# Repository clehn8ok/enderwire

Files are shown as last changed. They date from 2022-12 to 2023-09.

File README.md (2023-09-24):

# enderwire

This is an adaption of https://github.com/thomasfjen/enderwire_nonpro Files, with the following changes:
- Custom Toolhead -> Orbiter2 with a Rapido Hotend 
  - based on the Apogee Toolhead adapted onto the SW Carriage 
- right motor mount modified
  - shifts the whole motor towards the Z gantry, since the belt was not aligned with the OG mounts 
- simpler Enclosure design with only Acrylic, no double sided tap, everything is screwed 
- custom hinges, which open 180° 
- y carriage has now the holes for the cablechain in the right spot

Full build video:https://youtu.be/0t4zVtzr5Jg

2022-12-23_13h25_12
thumbnail_CL_3DPRINTER_YT






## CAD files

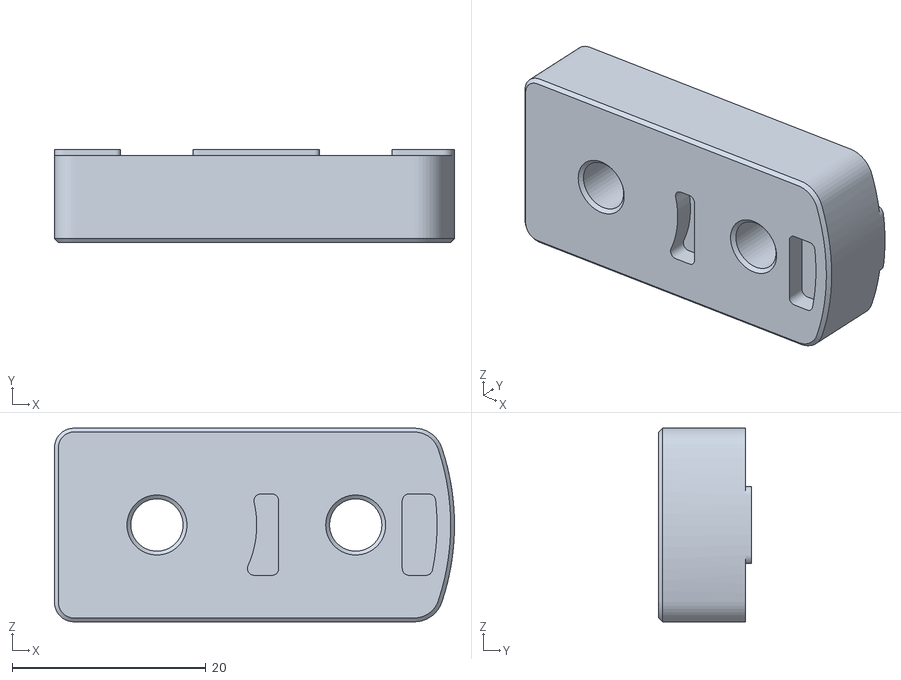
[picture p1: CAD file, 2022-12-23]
STLs/upperIdlerLH.stl
41.3 x 9.60 x 20.0

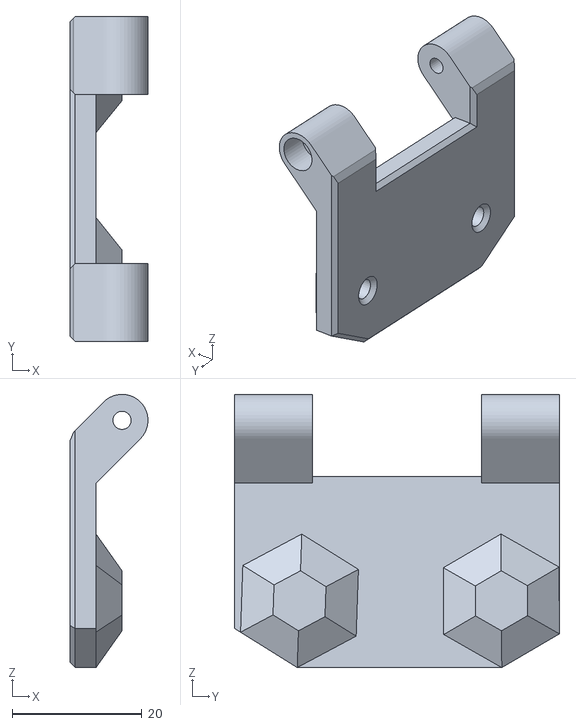
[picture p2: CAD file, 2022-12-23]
STLs/hinge2.stl
12.0 x 50.0 x 42.0

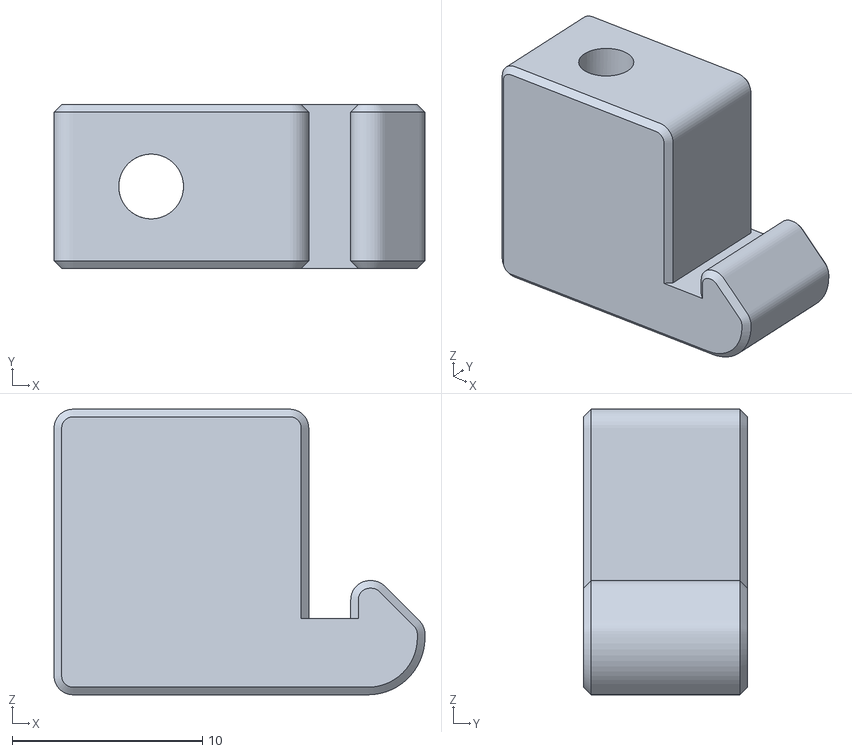
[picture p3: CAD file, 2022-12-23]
STLs/tensionerR.stl
19.5 x 8.60 x 15.0

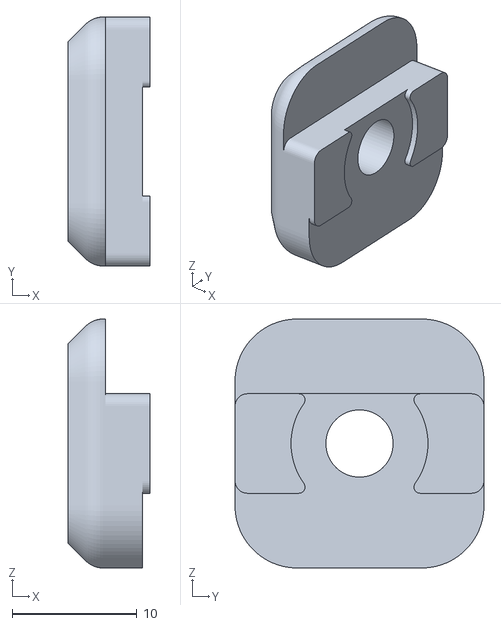
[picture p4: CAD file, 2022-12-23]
STLs/enclosureClip_L1.stl
6.60 x 20.0 x 20.0

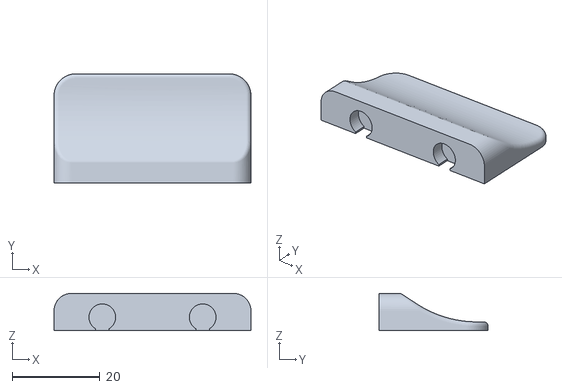
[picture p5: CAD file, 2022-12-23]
STLs/topDoor_magnetHOlder.stl
45.0 x 25.0 x 8.50

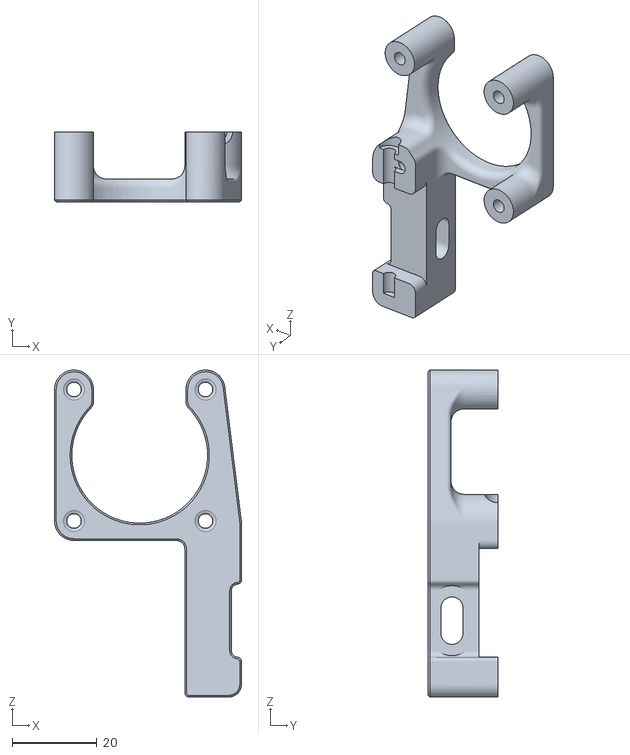
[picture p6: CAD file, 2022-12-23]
STLs/x_motorMountPart1R.stl
44.1 x 16.4 x 77.1

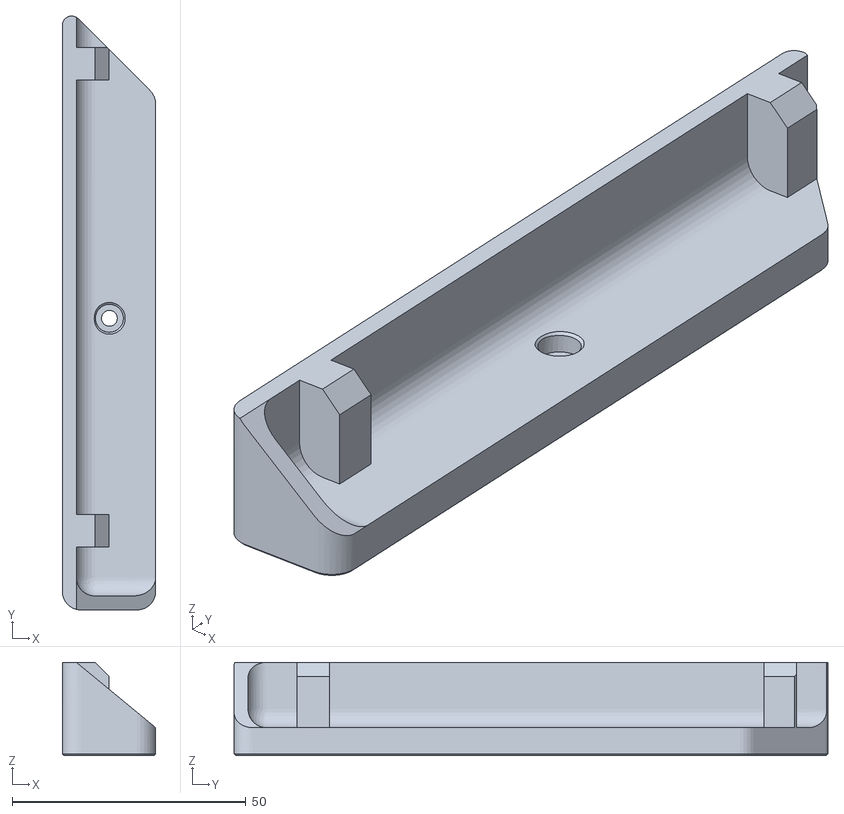
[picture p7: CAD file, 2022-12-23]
STLs/frontLowerSupportLeft.stl
20.0 x 127.2 x 20.0

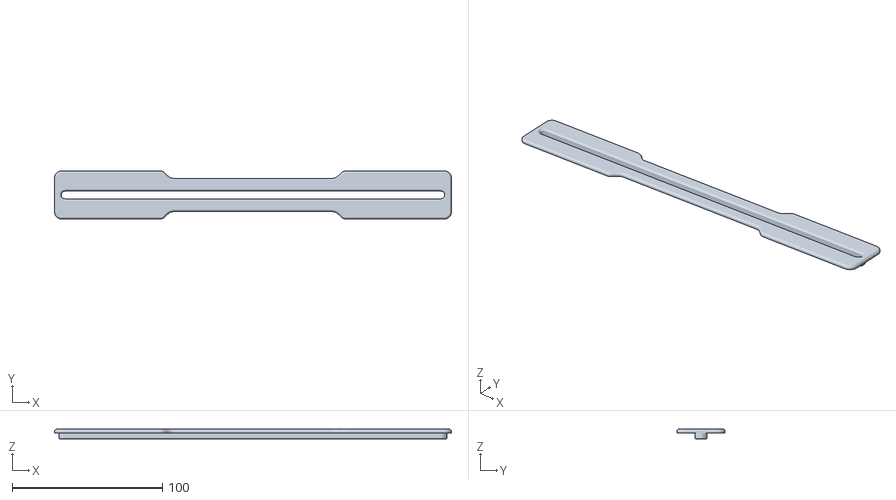
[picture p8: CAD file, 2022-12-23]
STLs/filamentFeed.stl
264.0 x 32.2 x 6.40

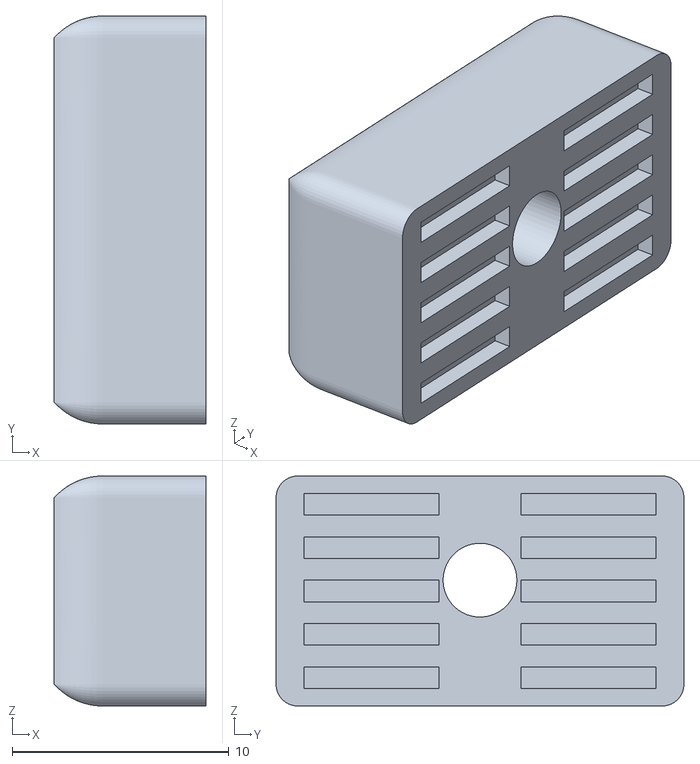
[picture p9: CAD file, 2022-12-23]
STLs/xCarriage_belt_quetscherR.stl
7.00 x 18.8 x 10.6

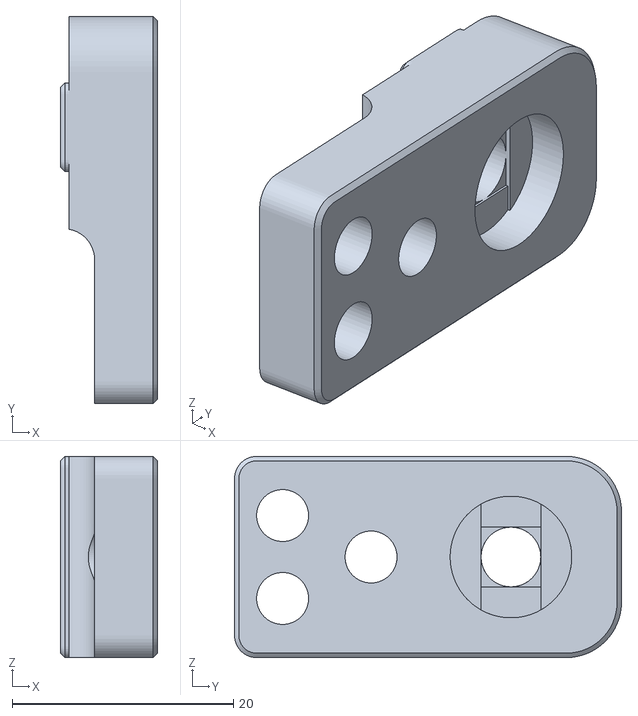
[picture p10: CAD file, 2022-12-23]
STLs/y_chainMount_frame.stl
8.80 x 35.0 x 18.2

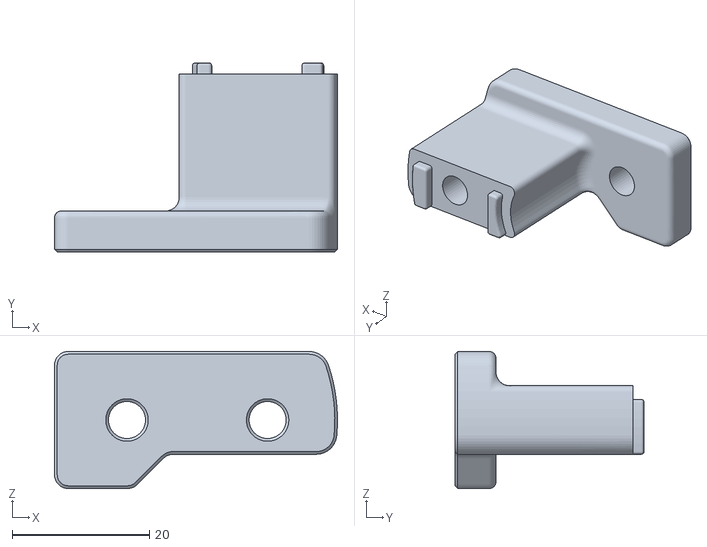
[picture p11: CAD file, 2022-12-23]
STLs/upperIdlerL.stl
41.3 x 27.6 x 20.0

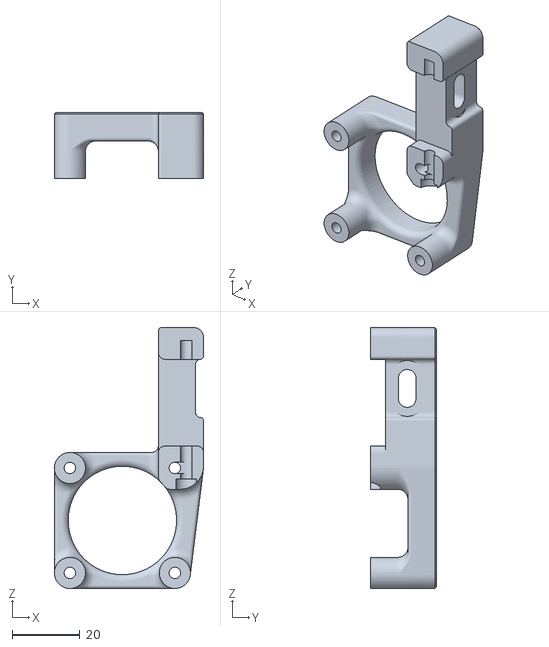
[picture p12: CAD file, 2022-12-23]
STLs/x_motorMountPart2L.stl
44.1 x 19.4 x 77.1

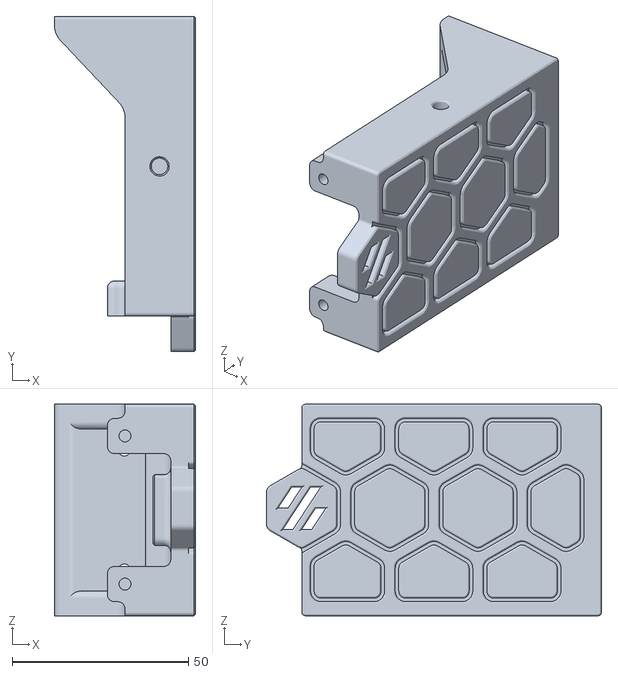
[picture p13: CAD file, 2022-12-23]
STLs/sideextension_rioghtfrontBreit_ganzVorne.stl
40.0 x 95.0 x 60.0

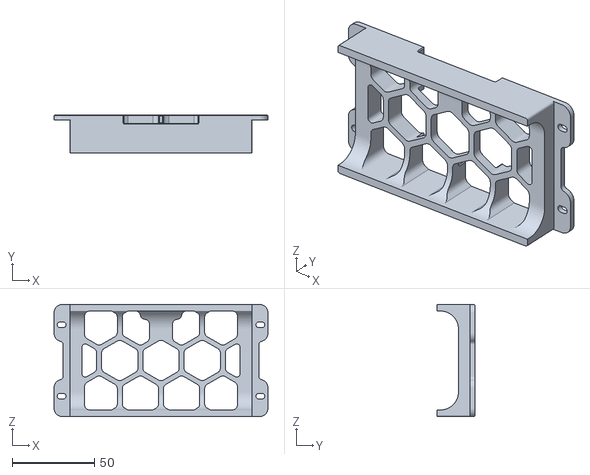
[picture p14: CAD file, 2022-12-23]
STLs/backgrillMiddle.stl
129.8 x 23.0 x 68.0

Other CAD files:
STLs/upperIdlerRH.stl
STLs/badge_HR.stl
STLs/test_print_carriage.stl
STLs/x_carriage_3.stl
STLs/1_y_axis_tensioner__upperPart_K_X_F6RPER3-9642_.stl
STLs/BL_touchHOlder.stl
STLs/Idler_mount.stl
STLs/PI_bracket.stl
STLs/backacrylPanelHolder.stl
STLs/badgeHL.stl
STLs/badgeVL.stl
STLs/badgeVR.stl
STLs/cablerelief.stl
STLs/cablerelief_new.stl
STLs/connection_plateSideGrill.stl
STLs/connection_plateSideGrill_right.stl
STLs/displayback.stl
STLs/displayfront.stl
STLs/enclosureClip_L.stl
STLs/enclosure_back_upper_connection.stl
STLs/fron_grill_connector.stl
STLs/frontLowerSupportright.stl
STLs/front_extension_vorneLinks.stl
STLs/front_extension_vornerechts.stl
STLs/front_grill_middle.stl
STLs/frontgrill_frontLeft.stl
STLs/hing1.stl
STLs/hinge1.stl
STLs/hingewasher1.stl
STLs/hingewasher2.stl
STLs/keybak1.stl
STLs/keybak2.stl
STLs/klickyWired#.stl
STLs/knob.stl
STLs/ledHolder_upperright.stl
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

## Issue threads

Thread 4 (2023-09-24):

Request: Add fusion file for of parts picking and assembly details.

ruankruger33, 2023-09-24:
I am trying to adapt your build to a CR 6se printer, may I request you add the Fusion file for ease of this process.

clehn8ok, 2023-09-24:
the fusion file is in the *.7z File enderwire_nonpro_0.2 v46.7z

Closed 2023-09-24.

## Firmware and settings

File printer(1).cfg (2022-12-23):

# This file contains common pin mappings for the BIGTREETECH SKR mini
# E3 v2.0. To use this config, the firmware should be compiled for the
# STM32F103 with a "28KiB bootloader" and USB communication. Also,
# select "Enable extra low-level configuration options" and configure
# "GPIO pins to set at micro-controller startup" to "!PA14".

# The "make flash" command does not work on the SKR mini E3. Instead,
# after running "make", copy the generated "out/klipper.bin" file to a
# file named "firmware.bin" on an SD card and then restart the SKR
# mini E3 with that SD card.

# See docs/Config_Reference.md for a description of parameters.

[printer]
kinematics: corexz
max_velocity: 500
max_accel: 3700
max_accel_to_decel: 3700
max_z_velocity: 50
max_z_accel: 1000
square_corner_velocity: 5

[mcu]
serial: /dev/serial/by-id/usb-Klipper_stm32f103xe_37FFD9054253373720501357-if00



[static_digital_output usb_pullup_enable]
pins: !PA14


#####################################################################
#   X Stepper Settings
#####################################################################

######
# Motor -XM
# Endstop - X-STOP
###############
[stepper_x]
step_pin: PB13
dir_pin: PB12
enable_pin: !PB14
rotation_distance: 40
full_steps_per_rotation: 200
microsteps: 32
endstop_pin: ^PC0
position_endstop: 216
position_min: 0
position_max: 216
homing_speed: 70
homing_positive_dir: true

[tmc2209 stepper_x]
uart_pin: PC11
tx_pin: PC10
uart_address: 0
run_current: 0.5
interpolate: False
stealthchop_threshold: 0

#####################################################################
#   Y Stepper Settings
#####################################################################

######
# Motor -YM
# Endstop - Y-STOP
###############
[stepper_y]
step_pin: PB10
dir_pin: PB2
enable_pin: !PB11
rotation_distance: 40
full_steps_per_rotation: 200
microsteps: 32
## Ucomment one of the following:
## Switch-based endstop for Y
endstop_pin: ^PC1 
## Sensorless endstop for Y
#endstop_pin: tmc2209_stepper_y:virtual_endstop
#homing_retract_dist: 0 # Uncomment this line too
position_endstop: 235
position_min: 0
position_max: 235
homing_speed: 70
homing_positive_dir: true

[tmc2209 stepper_y]
uart_pin: PC11
tx_pin: PC10
uart_address: 2
run_current: 0.5
interpolate: False
stealthchop_threshold: 0
## Uncomment if using sensorless Y homing.
#driver_SGTHRS: 120 # tune this once it's working.

#####################################################################
#   Z Stepper Settings
#####################################################################

######
# Motor -ZAM
# Endstop - Z-STOP
###############
[stepper_z]
step_pin: PB0
dir_pin: PC5
enable_pin: !PB1
rotation_distance: 40
full_steps_per_rotation: 200
microsteps: 32
endstop_pin: probe:z_virtual_endstop
position_max: 250
homing_speed: 70
position_min: -3.0

[tmc2209 stepper_z]
uart_pin: PC11
tx_pin: PC10
uart_address: 1
run_current: 0.5
interpolate: False
stealthchop_threshold: 0


[extruder]
step_pin: PB3
dir_pin: PB4
enable_pin: !PD2
microsteps: 16
rotation_distance: 4.637
nozzle_diameter: 0.400
filament_diameter: 1.750
max_extrude_only_distance:500
max_extrude_only_velocity:120

heater_pin: PC8
sensor_type: EPCOS 100K B57560G104F
sensor_pin: PA0
#control: pid
#pid_Kp: 21.527
#pid_Ki: 1.063
#pid_Kd: 108.982
min_temp: 0
max_temp: 250
pressure_advance:0.04
pressure_advance_smooth_time:0.03




[tmc2209 extruder]
uart_pin: PC11
tx_pin: PC10
uart_address: 3
interpolate:true
run_current: 0.850
hold_current:0.100
stealthchop_threshold: 0

[heater_bed]
heater_pin: PC9
sensor_type: EPCOS 100K B57560G104F
sensor_pin: PC3
#control: pid
#pid_Kp: 54.027
#pid_Ki: 0.770
#pid_Kd: 948.182
min_temp: 0
max_temp: 130


[fan]
pin: PC6

[bltouch]
stow_on_each_sample: True
sensor_pin: ^PC14
control_pin: PA1
x_offset:37.5
y_offset:0

speed: 10.0
pin_move_time: 0.675
pin_up_touch_mode_reports_triggered: True
pin_up_reports_not_triggered: True
lift_speed: 20 #80.0
samples_result: median
samples_tolerance: 0.015
samples_tolerance_retries: 8
stow_on_each_sample: False
sample_retract_dist: 0.8


#samples: 3   #Or higher if you want  
#pin_up_touch_mode_reports_triggered :false
#probe_with_touch_mode:false


[safe_z_home]
home_xy_position: 89.5, 127 # Change coordinates to the center of your print bed
speed: 300
z_hop: 10                 # Move up 10mm
z_hop_speed: 400


[bed_screws]
screw1: 0, 25
screw2: 210, 25
screw3: 210, 220
screw4: 0, 220

[screws_tilt_adjust]
screw1: 0, 25
screw1_name: front left screw
screw2: 180, 25
screw2_name: front right screw
screw3: 180, 220
screw3_name: rear right screw
screw4: 0, 220
screw4_name: rear left screw
horizontal_move_z: 10.
speed: 300.
screw_thread: CW-M3


[bed_mesh]
speed: 1000
horizontal_move_z: 5
mesh_min: 37.5, 5
mesh_max: 216, 220
probe_count: 6,6
algorithm: bicubic
fade_start: 1
fade_end: 10
fade_target: 0

[display]
#    FYSETC mini12864 LCD Display v2.1
lcd_type: uc1701
cs_pin: PB8
a0_pin: PB15
rst_pin: PB9
encoder_pins: ^PA9,^PA10
click_pin: ^!PB5
contrast: 63
spi_software_sclk_pin: PA5
spi_software_mosi_pin: PA7
spi_software_miso_pin: PA6

[neopixel fysetc_mini12864]
#    To control Neopixel RGB in mini12864 display
pin: PA15
chain_count: 3
initial_RED: 0.27
initial_GREEN: 0.72
initial_BLUE: 0.73
color_order: RGB

[heater_fan  hotendfan]
pin: PC7
heater_temp: 50.0




[virtual_sdcard]
path: ~/gcode_files

[pause_resume]


[display_status]





 

[temperature_sensor raspberry_pi]
sensor_type: temperature_host
min_temp: 10
max_temp: 100

[temperature_sensor mcu_temp]
sensor_type: temperature_mcu
min_temp: 0
max_temp: 100


[input_shaper]
shaper_freq_x: 77.4 # frequency for the X mark of the test model
shaper_type_x: mzv
shaper_freq_y:34.8# frequency for the Y mark of the test model
shaper_type_y: mzv



[mcu rpi]
serial: /tmp/klipper_host_mcu

[adxl345]
cs_pin: rpi:None

[resonance_tester]
accel_chip: adxl345
probe_points:
    115, 115, 20  # an example

#used for DSLR Timelapses
[firmware_retraction]
retract_length:0.5
retract_speed:120
unretract_speed:120


[include macro.cfg]
[include shell_command.cfg]

[respond]
default_type: command

#*# <---------------------- SAVE_CONFIG ---------------------->
#*# DO NOT EDIT THIS BLOCK OR BELOW. The contents are auto-generated.
#*#
#*# [extruder]
#*# control = pid
#*# pid_kp = 21.799
#*# pid_ki = 2.047
#*# pid_kd = 58.041
#*#
#*# [heater_bed]
#*# control = pid
#*# pid_kp = 74.214
#*# pid_ki = 1.026
#*# pid_kd = 1341.414
#*#
#*# [bltouch]
#*# z_offset = 3.394
#*#
#*# [bed_mesh default]
#*# version = 1
#*# points =
#*# 	  0.012500, -0.000000, -0.037500, -0.031250, -0.068750, 0.143750
#*# 	  0.012500, -0.012500, -0.037500, -0.037500, -0.087500, 0.100000
#*# 	  0.000000, -0.043750, -0.043750, -0.037500, -0.050000, 0.081250
#*# 	  -0.025000, -0.037500, -0.050000, -0.018750, -0.037500, 0.093750
#*# 	  -0.025000, -0.050000, -0.031250, -0.006250, -0.006250, 0.087500
#*# 	  0.025000, -0.012500, 0.025000, 0.050000, 0.050000, 0.137500
#*# x_count = 6
#*# y_count = 6
#*# mesh_x_pps = 2
#*# mesh_y_pps = 2
#*# algo = bicubic
#*# tension = 0.2
#*# min_x = 37.5
#*# max_x = 216.0
#*# min_y = 5.0
#*# max_y = 220.0

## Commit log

2022-12-23 initial Upload
    Ender3 to Switchwire Conversion based on https://github.com/thomasfjen/enderwire_nonpro
    [1_y_axis_tensioner__upperPart_K_X_F6RPER3-9642_.stl, BL_touchHOlder.stl, Idler_mount.stl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]
2022-12-23 KlipperConfig for the Enderwire
    [printer(1).cfg]
2023-01-20 DXF Files for the enclosure of an Ender3 SW
    you definetly need the whole cad file, since you need the 3d printed parts to assemble the enclosure
    pls double check, for me it worked, but for you it may not.
    The Fingerjoints are designed to be cut with a 2mm endmill, and therefore the fingerjoints have dogbones
